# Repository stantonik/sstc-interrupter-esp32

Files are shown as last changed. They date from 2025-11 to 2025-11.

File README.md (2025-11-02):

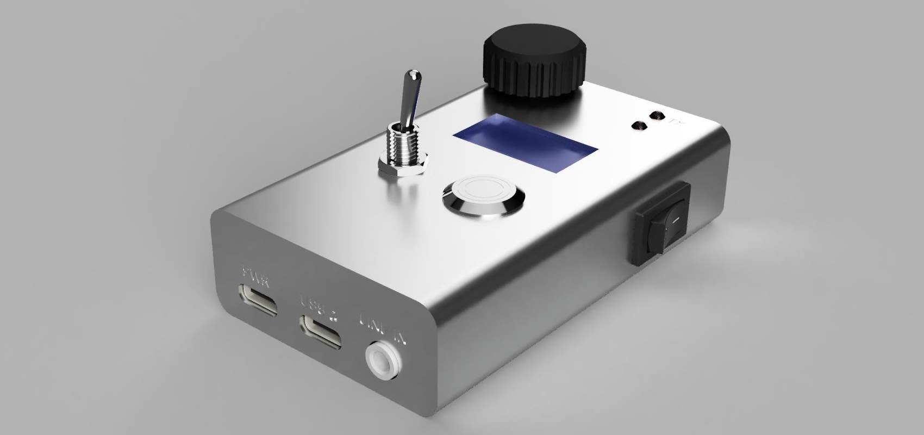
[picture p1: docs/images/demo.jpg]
demo


# sstc-interrupter-esp32

**Still in development! Maybe unstable.**

> This project implements a digital interrupter for any Solid State Tesla Coils (SSTC, DRSSTC, ...). The interrupter allows precise control over the arc output using different control modes, making it easy to experiment with pulse timing, audio modulation, or MIDI control.

## Features
- **Three Control Modes**
    - Manual: Fully custom PWM output from 0 to 20 kHz, with 1 µs minimum pulse width.
    - Line-In: Samples audio input via jack at 16 kHz, modulates PWM at 30 kHz carrier.
    - USB MIDI: Synthesizes sinusoidal notes, supports polyphonic chords, and modulates PWM at 30 kHz carrier.

- **User Interface**
    - SSD1306 64x128 monochrome display
    - Rotary encoder for navigation
    - Two triggers: toggle switch and push button
    - Nice and simple graphical interface

- **Connectivity**
    - USB-C for power input only
    - USB-C OTG/Serial for MIDI/Programming
    - 3.5 mm audio jack input
    - Toslink SPDIF output

- **Hardware Efficiency**
    - Written entirely in C using ESP-IDF
    - Real-time control via FreeRTOS
    - Optimized for ESP32-S3 hardware: LEDC, RMT, GPTIMER, ADC
    - Battery powered (200 mAh)

## RoadMap

- 📍 Implement advanced MIDI features (velocity, aftertouch)
- 📍 Implement real-time waveform visualization
- 📍 Add configuration presets and saving to flash

## Project Structure

``` text
sstc-interrupter-esp32/
├── LICENSE                   # Project license
├── README.md                 # This file
├── docs/                     # Documentation, schematics, and guides
├── firmware/                 # ESP-IDF firmware project
│   ├── CMakeLists.txt
│   ├── dependencies.lock
│   ├── main/
│   │   ├── CMakeLists.txt
│   │   ├── Kconfig.projbuild # Custom menuconfig for pinout & constraints
│   │   ├── app/              # High-level application logic
│   │   │   ├── clients/      # Protocol clients (e.g., USB MIDI)
│   │   │   ├── gui/          # Graphical User Interface (LVGL)
│   │   │   └── main.c        # Program entry point (init, orchestrate, ...)
│   │   ├── core/             # Event handling
│   │   ├── hal/              # Hardware Abstraction Layer (synth, USB, display, jack, etc.)
│   │   └── idf_component.yml
│   ├── sdkconfig
│   └── sstc_interrupter-esp32.eez-project # EEZ-Studio project for LVGL GUI design
└── hardware/
    ├── cad/                  # 3D models, STLs, and mechanical design
    └── pcb/                  # Printed Circuit Board designs and gerbers
```

## Documentation
***soon***

## Contributing
Contributions are welcome! You can help by:
- Reporting issues or bugs
- Improving UI graphics
- Optimizing PWM and audio processing
- Adding features (more control modes, presets, etc.)
- Updating documentation and schematics

**Please note:** This project involves high-voltage electronics. Take appropriate safety precautions and ensure optical isolation between the interrupter and the Tesla coil.

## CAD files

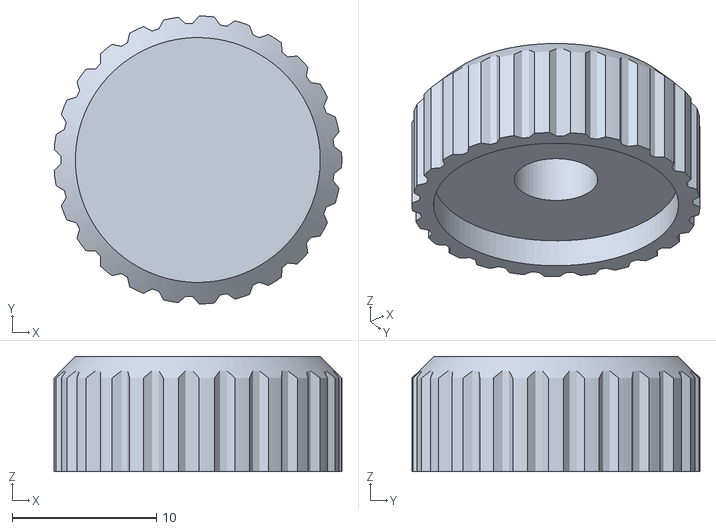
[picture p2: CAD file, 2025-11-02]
hardware/cad/stl/knob.stl
20.0 x 20.0 x 8.00

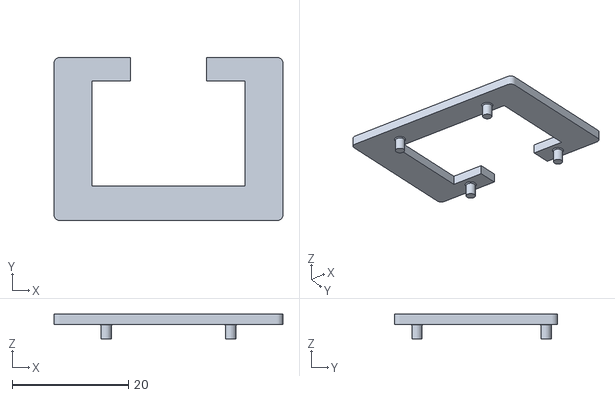
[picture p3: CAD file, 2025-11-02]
hardware/cad/stl/screen-support.stl
39.4 x 28.1 x 4.30

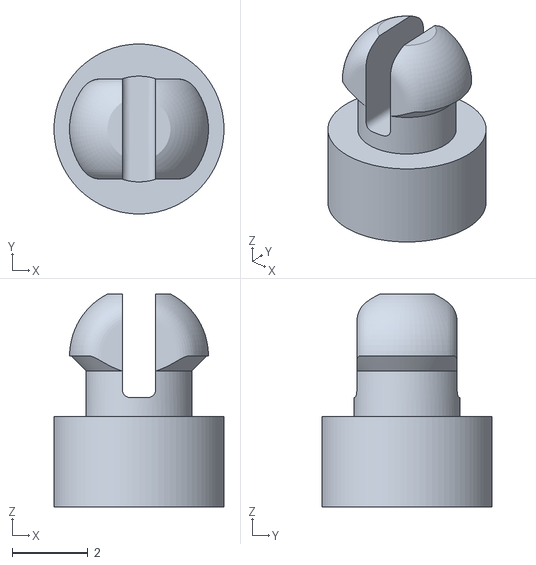
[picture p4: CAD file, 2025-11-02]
hardware/cad/stl/pcb-snap_support.stl
4.50 x 4.50 x 5.64

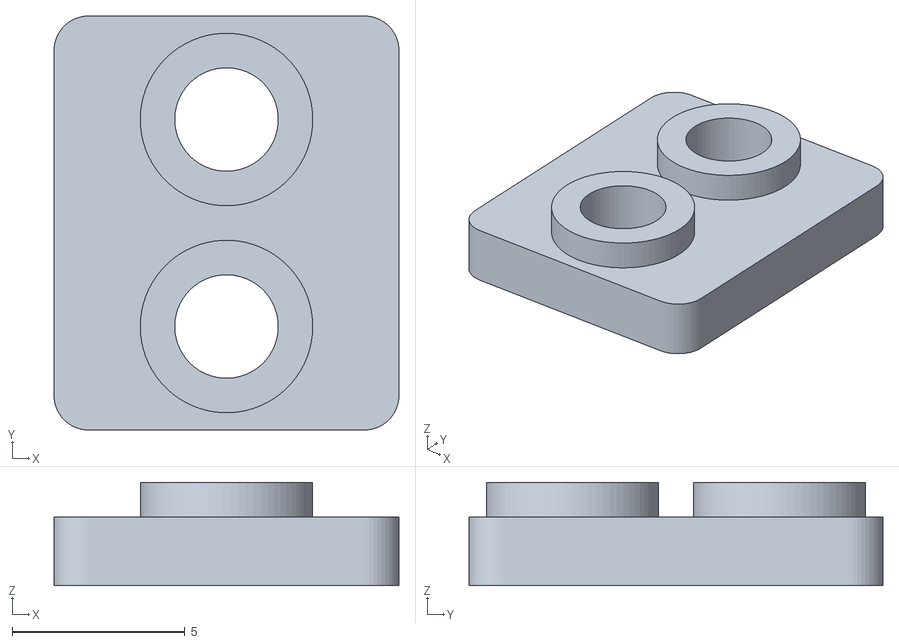
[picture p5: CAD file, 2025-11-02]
hardware/cad/stl/leds-support.stl
10.0 x 12.0 x 3.00

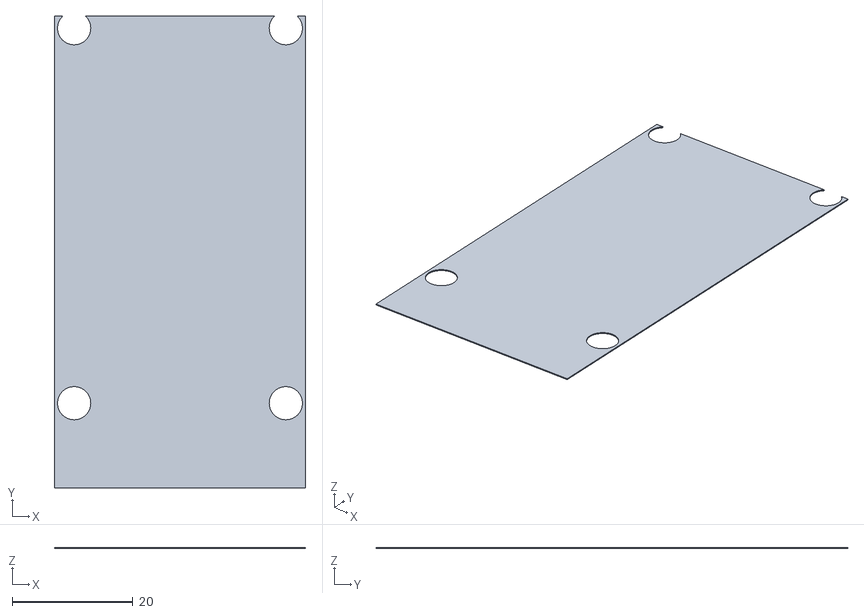
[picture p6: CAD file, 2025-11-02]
hardware/cad/stl/isolate-layer.stl
41.5 x 78.0 x 0.18

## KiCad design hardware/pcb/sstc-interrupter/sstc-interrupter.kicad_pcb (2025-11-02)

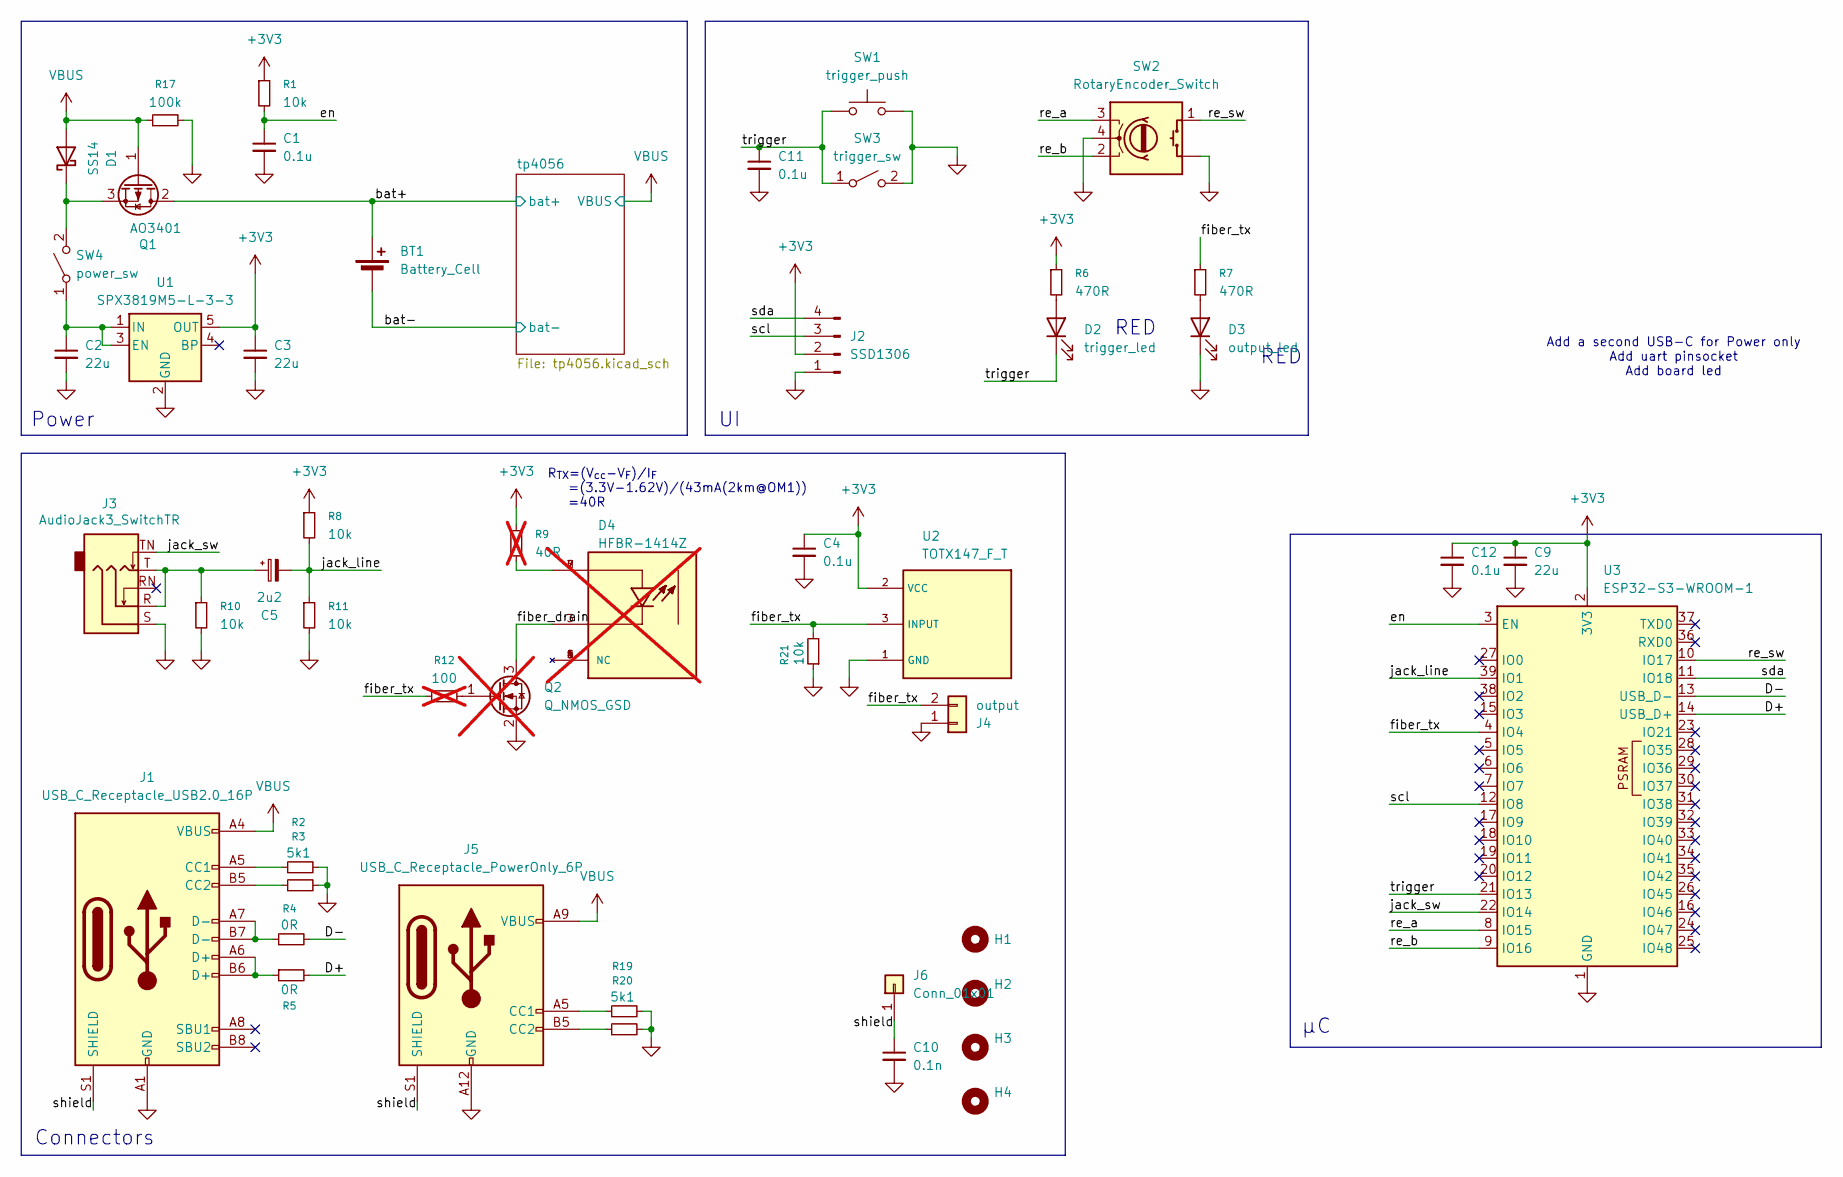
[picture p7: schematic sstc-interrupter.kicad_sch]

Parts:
BT1: Battery_Cell; JST_PH_B2B-PH-K_1x02_P2.00mm_Vertical
C1, C4, C11, C12: 0.1u; C_0603_1608Metric_Pad1.08x0.95mm_HandSolder
C2, C3, C9: 22u; C_0805_2012Metric_Pad1.18x1.45mm_HandSolder
C5: 2u2; C_Radial_D5.0mm_H11.0mm_P2.00mm
C10: 0.1n; C_0805_2012Metric_Pad1.18x1.45mm_HandSolder
D1: SS14; D_SMA
D2: trigger_led; JST_PH_B2B-PH-K_1x02_P2.00mm_Vertical
D3: output_led; JST_PH_B2B-PH-K_1x02_P2.00mm_Vertical
D4: HFBR-1414Z; OPTO_HFBR-1414Z; PARTREV February 15, 2019; not fitted
H1, H2, H3, H4: MountingHole; MountingHole_3.2mm_M3_DIN965
J1: USB_C_Receptacle_USB2.0_16P; USB_C_Receptacle_GCT_USB4105-xx-A_16P_TopMnt_Horizontal
J2: SSD1306; JST_PH_B4B-PH-K_1x04_P2.00mm_Vertical
J3: AudioJack3_SwitchTR; Jack_3.5mm_CUI_SJ1-3525N_Horizontal
J4: output; PinHeader_1x02_P2.54mm_Horizontal
J5: USB_C_Receptacle_PowerOnly_6P; USB_C_Receptacle_GCT_USB4125-xx-x-0190_6P_TopMnt_Horizontal
J6: Conn_01x01; SolderWire-0.15sqmm_1x01_D0.5mm_OD1.5mm
Q1: AO3401; SOT-23_Handsoldering
Q2: Q_NMOS_GSD; SOT-23-3; not fitted
R1, R8, R10, R11, R21: 10k; R_0603_1608Metric_Pad0.98x0.95mm_HandSolder
R2, R3, R19, R20: 5k1; R_0603_1608Metric_Pad0.98x0.95mm_HandSolder
R4, R5: 0R; R_0603_1608Metric_Pad0.98x0.95mm_HandSolder
R6, R7: 470R; R_0603_1608Metric_Pad0.98x0.95mm_HandSolder
R9: 40R; R_0603_1608Metric_Pad0.98x0.95mm_HandSolder; not fitted
R12: 100; R_0603_1608Metric_Pad0.98x0.95mm_HandSolder; not fitted
R17: 100k; R_0603_1608Metric_Pad0.98x0.95mm_HandSolder
SW1: trigger_push; JST_PH_B2B-PH-K_1x02_P2.00mm_Vertical
SW2: RotaryEncoder_Switch; JST_PH_B4B-PH-K_1x04_P2.00mm_Vertical
SW3: trigger_sw; JST_PH_B2B-PH-K_1x02_P2.00mm_Vertical
SW4: power_sw; JST_PH_B2B-PH-K_1x02_P2.00mm_Vertical
U1: SPX3819M5-L-3-3; SOT-23-5
U2: TOTX147_F_T; TOSHIBA_TORX147_F_T_
U3: ESP32-S3-WROOM-1; ESP32-S3-WROOM-1U

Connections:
+3V3: C3.1, C4.1, C9.1, C12.1, J2.2, R1.1, R6.1, R8.1, R9.1, U1.5 (OUT), U2.2 (VCC), U3.2 (3V3)
/D+: R5.2, U3.14 (USB_D+)
/D-: R4.2, U3.13 (USB_D-)
/bat+: BT1.1 (+), Q1.2 (D); also elsewhere on the board
/bat-: BT1.2 (-); also elsewhere on the board
/en: C1.1, R1.2, U3.3 (EN)
/fiber_tx: J4.2, R7.1, R12.1, R21.2, U2.3 (INPUT), U3.4 (IO4)
/jack_line: C5.2, R8.2, R11.1, U3.39 (IO1)
/jack_sw: J3.TN, U3.22 (IO14)
/re_a: SW2.3 (A), U3.8 (IO15)
/re_b: SW2.2 (B), U3.9 (IO16)
/re_sw: SW2.1 (S1), U3.10 (IO17)
/scl: J2.3, U3.12 (IO8)
/sda: J2.4, U3.11 (IO18)
/shield: C10.1, J1.S1 (SHIELD), J5.S1 (SHIELD), J6.1
/trigger: C11.1, D2.2 (K), SW1.1, SW3.1 (A), U3.21 (IO13)
GND: C1.2, C2.2, C3.2, C4.2, C9.2, C10.2, C11.2, C12.2, D3.1 (K), J1.A1 (GND), J1.A12 (GND), J1.B1 (GND), J1.B12 (GND), J2.1, J3.S, J4.1, J5.A12 (GND), J5.B12 (GND), Q2.2 (S), R2.2, R3.2, R10.2, R11.2, R17.2, R19.2, R20.2, R21.1, SW1.2, SW2. (S2), SW2.4 (C), SW3.2 (B), U1.2 (GND), U2.1 (GND), U3.1 (GND), U3.40 (GND), U3.41 (GND); also elsewhere on the board
unnamed: C5.1, J3.R, J3.T, R10.1
unnamed: D1.1 (K), Q1.3 (S), SW4.2 (B)
unnamed: D2.1 (A), R6.2
unnamed: D3.2 (A), R7.2
unnamed: D4.1 (NC), D4.4 (NC), D4.5 (NC), D4.8 (NC)
unnamed: D4.2, D4.6, D4.7, R9.2
unnamed: D4.3, Q2.3 (D)
unnamed: J1.A5 (CC1), R2.1
unnamed: J1.B5 (CC2), R3.1
unnamed: J1.A6 (D+), J1.B6 (D+), R5.1
unnamed: J1.A7 (D-), J1.B7 (D-), R4.1
unnamed: J5.A5 (CC1), R19.1
unnamed: J5.B5 (CC2), R20.1
unnamed: Q2.1 (G), R12.2
unnamed: C2.1, SW4.1 (A), U1.1 (IN), U1.3 (EN)
VBUS: D1.2 (A), J1.A4 (VBUS), J1.A9 (VBUS), J1.B4 (VBUS), J1.B9 (VBUS), J5.A9 (VBUS), J5.B9 (VBUS), Q1.1 (G), R17.1; also elsewhere on the board

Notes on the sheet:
Add a second USB-C for Power only Add uart pinsocket Add board led
Connectors
R_{TX}=(V_{cc}-V_{F})/I_{F} =(3.3V-1.62V)/(43mA(2km@OM1)) =40R
RED
Power

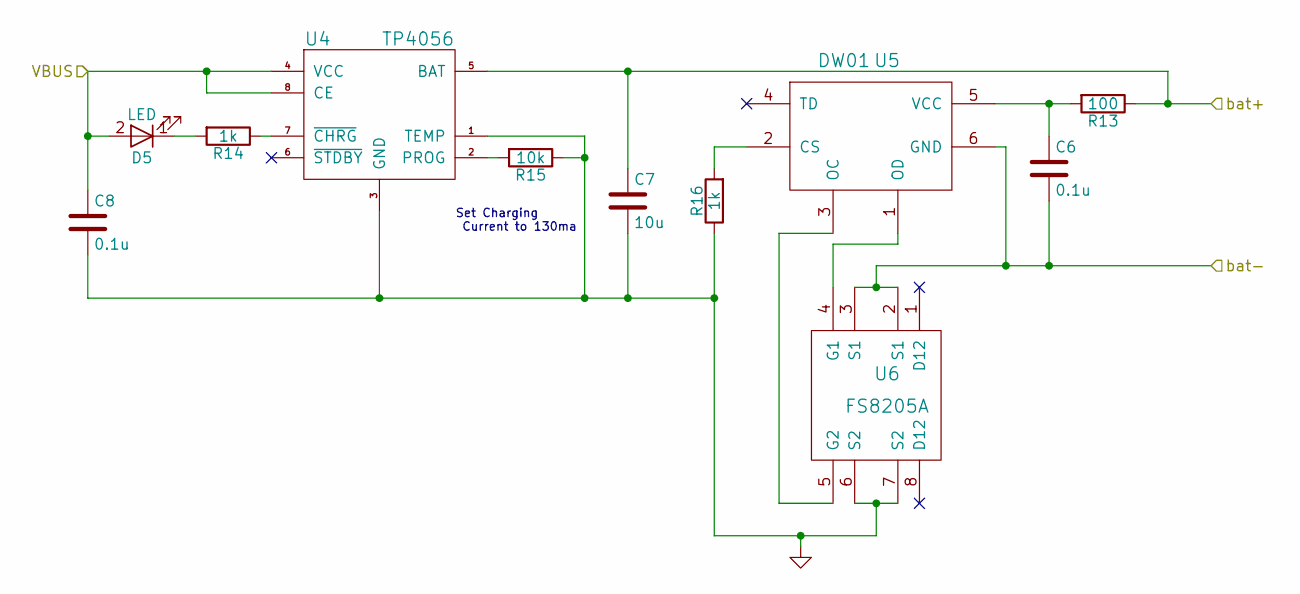
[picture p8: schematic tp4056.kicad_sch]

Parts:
C6, C8: 0.1u; C_0603_1608Metric_Pad1.08x0.95mm_HandSolder
C7: 10u; C_0805_2012Metric_Pad1.18x1.45mm_HandSolder
D5: LED; LED_0603_1608Metric_Pad1.05x0.95mm_HandSolder
R13: 100; R_0603_1608Metric_Pad0.98x0.95mm_HandSolder
R14, R16: 1k; R_0603_1608Metric_Pad0.98x0.95mm_HandSolder
R15: 10k; R_0603_1608Metric_Pad0.98x0.95mm_HandSolder
U4: TP4056; SOP-8_3.9x4.9mm_P1.27mm
U5: DW01; SOT-23-6_Handsoldering
U6: FS8205A; TSSOP-8_4.4x3mm_P0.65mm

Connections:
/bat+: C7.1, R13.1, U4.5 (BAT); also elsewhere on the board
/bat-: C6.2, U5.6 (GND), U6.2 (S1), U6.3 (S1); also elsewhere on the board
GND: C7.2, C8.2, R15.1, R16.1, U4.1 (TEMP), U4.3 (GND), U6.6 (S2), U6.7 (S2); also elsewhere on the board
unnamed: D5.1 (K), R14.2
unnamed: R15.2, U4.2 (PROG)
unnamed: R14.1, U4.7 (~CHRG)
unnamed: R16.2, U5.2 (CS)
unnamed: U5.3 (OC), U6.5 (G2)
unnamed: U5.1 (OD), U6.4 (G1)
unnamed: C6.1, R13.2, U5.5 (VCC)
VBUS: C8.1, D5.2 (A), U4.4 (VCC), U4.8 (CE); also elsewhere on the board

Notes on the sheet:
Set Charging Current to 130ma

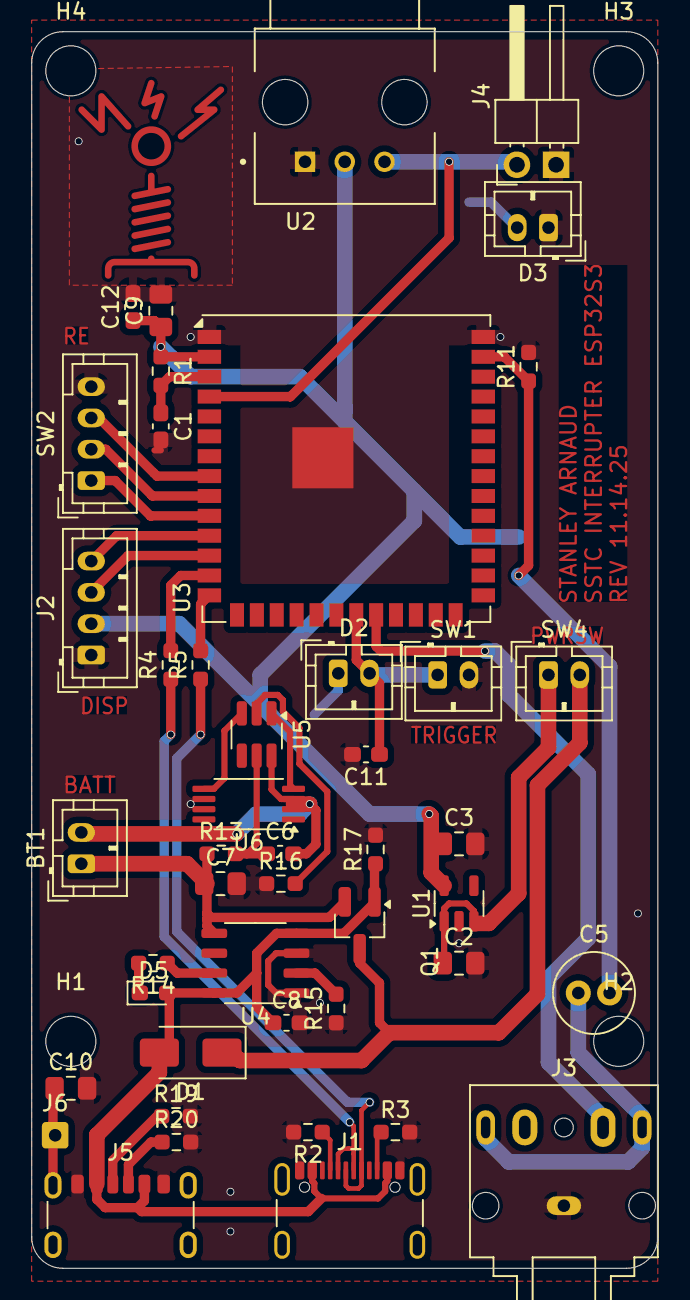
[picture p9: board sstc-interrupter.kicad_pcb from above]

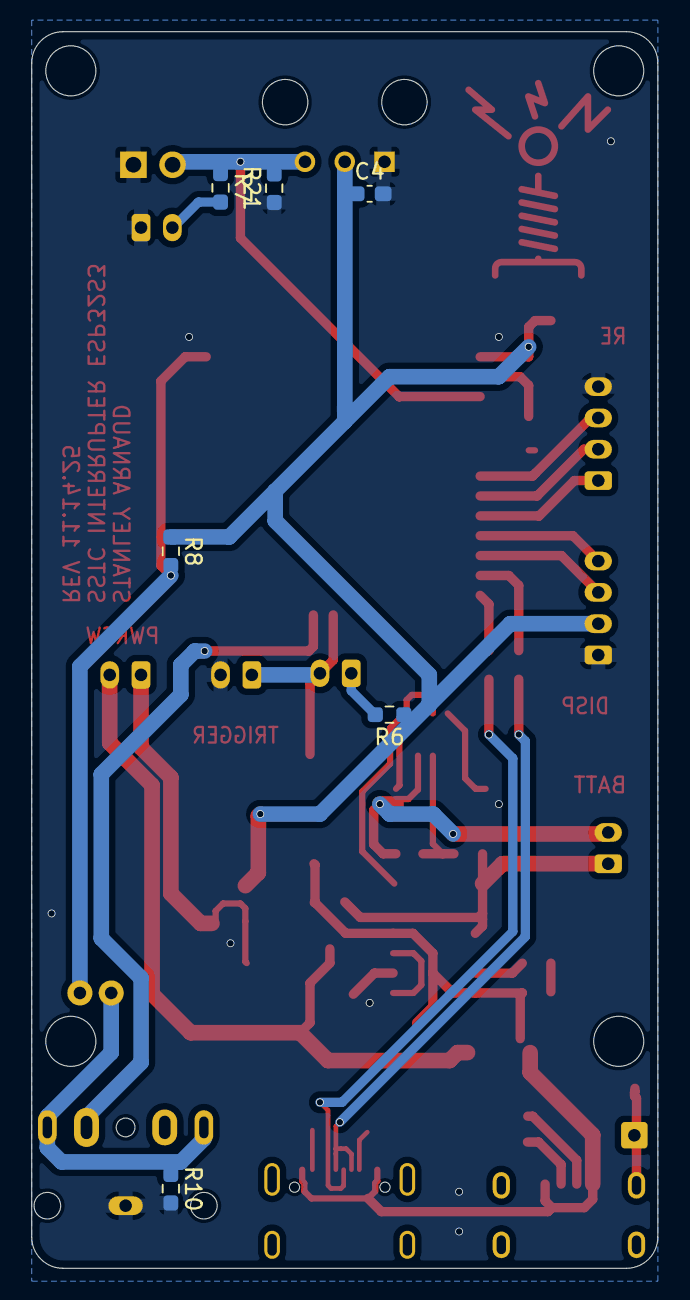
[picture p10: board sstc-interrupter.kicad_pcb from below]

Board: 2 copper layers, 40.0 x 79.0 mm, 55 parts (6 on the bottom side), 36 nets.

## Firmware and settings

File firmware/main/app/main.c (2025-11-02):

/*
 * Copyright (C) 2025 Stanley Arnaud <stantonik@stantonik-mba.local>
 *
 * Distributed under terms of the MIT license.
 */

/**
 * @file main.c
 * @brief
 *
 * @author Stanley Arnaud
 * @date 10/25/2025
 * @version 0
 */

// -----------------------------------------------------------------------------
// Includes
// -----------------------------------------------------------------------------
#include "app/clients/usb_midi.h"
#include "app/gui/knobs.h"
#include "clients/usb_midi.h"
#include "core/event_bus.h"
#include "esp_attr.h"
#include "esp_log.h"
#include "freertos/idf_additions.h"
#include "gui/menu.h"
#include "hal/audio_jack.h"
#include "hal/controls.h"
#include "hal/display.h"
#include "hal/pwm.h"
#include "hal/synth.h"
#include "hal/usb.h"

// -----------------------------------------------------------------------------
// Macros and Constants
// -----------------------------------------------------------------------------
#define TAG "main"

#define RETURN_ON_ERROR(x)                                                                                             \
    {                                                                                                                  \
        esp_err_t ret = (x);                                                                                           \
        if (ret != ESP_OK) return;                                                                                     \
    }

// -----------------------------------------------------------------------------
// Static Variables
// -----------------------------------------------------------------------------

// -----------------------------------------------------------------------------
// Static Function Declarations
// -----------------------------------------------------------------------------

// -----------------------------------------------------------------------------
// Static Function Definitions
// -----------------------------------------------------------------------------
static void midi_on_receive_cb(midi_message_t msg)
{
    if (menu_get_mode() != MENU_MODE_MIDI) return;

    static synth_note_t synth_note = {0};
    synth_note.note = msg.note % 12;
    synth_note.octave = -2 + msg.note / 12;

    if (msg.state == 1)
    {
        synth_play_note(synth_note);

        midi_msg_parsed_t parsed_msg = usb_midi_parse_msg(&msg);

        char header[16];
        snprintf(header, 16, "%s%d", parsed_msg.note, parsed_msg.octave);
        menu_set_header_text(header);
    }
    else
    {
        synth_stop_note(synth_note);
        menu_set_header_text("");
    }
}

static void knobs_on_change_cb(knobs_mask_t updated, const knob_t *knobs[])
{
    static float prf = 0;
    static uint16_t pd = 0;

    if (updated & (1 << KNOB_PRF))
    {
        prf = knobs[KNOB_PRF]->value;
    }
    if (updated & (1 << KNOB_PD))
    {
        pd = knobs[KNOB_PD]->value;
    }

    ESP_LOGI(TAG, "prf=%d, pd=%d", (int)prf, (int)pd);
    pwm_manual_update(prf, pd);
}

static IRAM_ATTR void audio_jack_out_cb(uint16_t value)
{
    // Get knob pointers
    const knob_t *knobs[KNOB_COUNT];
    knobs_get_values(knobs);

    // Center input around mid
    int16_t centered_val = (int16_t)value - AUDIO_JACK_OUT_MID;

    // Apply pseudo-exponential gain for GDB knob
    int16_t gdb = knobs[KNOB_GDB]->value;  // Gdb range: -50..+50
    int32_t temp = centered_val;
    if (gdb > 0) {
        temp = temp + (temp * gdb * gdb) / 2500; // stronger amplification
    } else if (gdb < 0) {
        temp = temp - (temp * gdb * gdb) / 2500; // stronger attenuation
    }
    centered_val = (int16_t)temp;

    // Add mid back
    int16_t val = centered_val + AUDIO_JACK_OUT_MID;

    // Clamp to valid output range
    if (val < 0) val = 0;
    if (val > AUDIO_JACK_OUT_MAX) val = AUDIO_JACK_OUT_MAX;

    // Convert to PWM duty (uint8_t) and apply power knob
    uint32_t dt = (uint32_t)val * PWM_MOD_DUTY_MAX / AUDIO_JACK_OUT_MAX;
    dt = dt * knobs[KNOB_PWR]->value / knobs[KNOB_PWR]->max_physical;

    // Update PWM
    pwm_modulation_update((uint8_t)(dt / 2));
}

static IRAM_ATTR void synth_on_sampling_cb(uint16_t value)
{
    const knob_t *knobs[KNOB_COUNT];
    knobs_get_values(knobs);

    uint32_t dt = (uint32_t)value * PWM_MOD_DUTY_MAX / SYNTH_OUT_MAX;
    dt = dt * knobs[KNOB_PWR]->value / knobs[KNOB_PWR]->max_physical;
    pwm_modulation_update((uint8_t)(dt / 2));
}

// -----------------------------------------------------------------------------
// Function Definitions
// -----------------------------------------------------------------------------
void app_main(void)
{
    ESP_LOGI(TAG, "Firmware starting...");

    // Initialize Serial bridge at first
    RETURN_ON_ERROR(usb_init_serial());

    // Create event queue
    RETURN_ON_ERROR(event_bus_init());

    // Initialize hardware
    RETURN_ON_ERROR(controls_init());
    RETURN_ON_ERROR(audio_jack_init());
    RETURN_ON_ERROR(display_init());
    RETURN_ON_ERROR(pwm_init());
    audio_jack_set_output_cb(audio_jack_out_cb);

    uint8_t ctrl_state = controls_get_state();

    // Initialize GUI
    RETURN_ON_ERROR(menu_init());
    knobs_set_on_change_cb(knobs_on_change_cb);
    RETURN_ON_ERROR(knobs_init());

    // Check if trigger was pressed on boot
    if (ctrl_state & CONTROLS_FLAG_TRIGGER_PRESSED)
    {
        menu_display_msg_box("Release trigger\non boot!", 0);
        ESP_LOGI(TAG, "Triggered on boot! Please release it.");
        while (ctrl_state & CONTROLS_FLAG_TRIGGER_PRESSED)
        {
            ctrl_state = controls_get_state();
            vTaskDelay(pdMS_TO_TICKS(10));
        }
        menu_hide_msg_box();
    }

    // Configure USB Host Library if encoder switch was not pressed on boot
    if (ctrl_state & CONTROLS_FLAG_RE_PRESSED)
    {
        menu_display_msg_box("Debug mode\n(MIDI disabled)", 1500);
        ESP_LOGI(TAG, "Booted in debug mode (MIDI disabled)");
    }
    else
    {
        ESP_LOGI(TAG, "Booted in normal operation");
        RETURN_ON_ERROR(usb_free_serial());
        if (usb_init_host() != ESP_OK)
        {
            usb_init_serial();
            ESP_LOGW(TAG, "Could not install USB host");
        }

        RETURN_ON_ERROR(usb_midi_init());
        usb_midi_set_on_receive_cb(midi_on_receive_cb);

        RETURN_ON_ERROR(synth_init());
        synth_set_on_sampling_cb(synth_on_sampling_cb);
    }

    event_t e;
    while (1)
    {
        event_bus_dispatch(&e, portMAX_DELAY);

        if (e.source == EVENT_SRC_CONTROLS)
        {
            switch (e.type)
            {
            case CONTROLS_EVENT_TRIGGER_PRESSED:
                ESP_LOGI(TAG, "Armed");
                menu_set_state(MENU_STATE_ARMED);
                pwm_enable();
                break;
            case CONTROLS_EVENT_TRIGGER_RELEASED:
                ESP_LOGI(TAG, "Disarmed");
                menu_set_state(MENU_STATE_IDLE);
                pwm_disable();
                break;
            default:
                break;
            }
        }
        else if (e.source == EVENT_SRC_AUDIO_JACK)
        {
            switch (e.type)
            {
            case AUDIO_JACK_EVENT_PLUGGED:
                if (menu_get_mode() != MENU_MODE_MANUAL) break;
                ESP_LOGI(TAG, "Line-IN mode");
                menu_set_mode(MENU_MODE_AUDIO_JACK, true);
                audio_jack_start_listen();
                pwm_set_mode(PWM_MODE_MODULATION);
                break;
            case AUDIO_JACK_EVENT_UNPLUGGED:
                if (menu_get_mode() != MENU_MODE_AUDIO_JACK) break;
                ESP_LOGI(TAG, "Manual mode");
                menu_set_mode(MENU_MODE_MANUAL, true);
                audio_jack_stop_listen();
                pwm_set_mode(PWM_MODE_MANUAL);
                break;
            default:
                break;
            }
        }
        else if (e.source == EVENT_SRC_USB_MIDI)
        {
            switch (e.type)
            {
            case USB_MIDI_EVENT_CONNECTED:
                if (menu_get_mode() != MENU_MODE_MANUAL) break;
                ESP_LOGI(TAG, "MIDI mode");
                menu_set_mode(MENU_MODE_MIDI, true);
                pwm_set_mode(PWM_MODE_MODULATION);
                synth_enable();
                break;
            case USB_MIDI_EVENT_DISCONNECTED:
                if (menu_get_mode() != MENU_MODE_MIDI) break;
                ESP_LOGI(TAG, "Manual mode");
                menu_set_mode(MENU_MODE_MANUAL, true);
                synth_disable();
                pwm_set_mode(PWM_MODE_MANUAL);
                break;
            default:
                break;
            }
        }
    }

    ESP_LOGI(TAG, "Firmware exited");
}

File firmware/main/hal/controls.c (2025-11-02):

/*
 * Copyright (C) 2025 Stanley Arnaud <stantonik@stantonik-mba.local>
 *
 * Distributed under terms of the MIT license.
 */

/**
 * @file controls.c
 * @brief
 *
 * @author Stanley Arnaud
 * @date 10/24/2025
 * @version 0
 */

// -----------------------------------------------------------------------------
// Includes
// -----------------------------------------------------------------------------
#include "controls.h"
#include "esp_log.h"
#include "freertos/FreeRTOS.h"
#include "button_gpio.h"
#include "core/event_bus.h"
#include "encoder.h"
#include "esp_check.h"
#include "iot_button.h"

// -----------------------------------------------------------------------------
// Macros and Constants
// -----------------------------------------------------------------------------
#define TAG "controls"

#define PIN_TRIGGER CONFIG_INTERRUPTER_PIN_TRIGGER

#define PIN_RE_A CONFIG_INTERRUPTER_PIN_RE_A
#define PIN_RE_B CONFIG_INTERRUPTER_PIN_RE_B
#define PIN_RE_SW CONFIG_INTERRUPTER_PIN_RE_SW

// -----------------------------------------------------------------------------
// Static Variables
// -----------------------------------------------------------------------------
static rotary_encoder_t re = {0};
static QueueHandle_t re_queue = NULL;

static button_handle_t trigger_btn = NULL;

static volatile uint8_t state = 0;

// -----------------------------------------------------------------------------
// Static Function Declarations
// -----------------------------------------------------------------------------

// -----------------------------------------------------------------------------
// Static Function Definitions
// -----------------------------------------------------------------------------
static void button_down_cb(void *arg, void *usr_data)
{
    button_handle_t btn = (button_handle_t)arg;
    event_t event = {.source = EVENT_SRC_CONTROLS};

    if (btn == trigger_btn)
    {
        ESP_LOGI(TAG, "Trigger pressed");
        state |= CONTROLS_FLAG_TRIGGER_PRESSED;
        event.type = CONTROLS_EVENT_TRIGGER_PRESSED;
    }

    event_bus_publish(&event);
}

static void button_up_cb(void *arg, void *usr_data)
{
    button_handle_t btn = (button_handle_t)arg;
    event_t event = {.source = EVENT_SRC_CONTROLS};

    if (btn == trigger_btn)
    {
        ESP_LOGI(TAG, "Trigger released");
        state &= ~CONTROLS_FLAG_TRIGGER_PRESSED;
        event.type = CONTROLS_EVENT_TRIGGER_RELEASED;
    }

    event_bus_publish(&event);
}

static void re_task(void *pvParam)
{
    rotary_encoder_event_t re_event;
    event_t event = {.source = EVENT_SRC_CONTROLS};

    while (1)
    {
        xQueueReceive(re_queue, &re_event, portMAX_DELAY);

        switch (re_event.type)
        {
        case RE_ET_BTN_PRESSED:
            event.type = CONTROLS_EVENT_RE_BTN_PRESSED;
            state |= CONTROLS_FLAG_RE_PRESSED;
            break;
        case RE_ET_BTN_RELEASED:
            event.type = CONTROLS_EVENT_RE_BTN_RELEASED;
            state &= ~CONTROLS_FLAG_RE_PRESSED;
            break;
        case RE_ET_BTN_CLICKED:
            event.type = CONTROLS_EVENT_RE_BTN_CLICKED;
            break;
        case RE_ET_BTN_LONG_PRESSED:
            event.type = CONTROLS_EVENT_RE_BTN_LONG_PRESSED;
            break;
        case RE_ET_CHANGED:
            event.type = CONTROLS_EVENT_RE_CHANGED;
            event.value = re_event.diff;
            break;
        default:
            break;
        }

        event_bus_publish(&event);
    }
}

// -----------------------------------------------------------------------------
// Function Definitions
// -----------------------------------------------------------------------------
esp_err_t controls_init(void)
{
    // Rotary encoder
    re_queue = xQueueCreate(4, sizeof(rotary_encoder_event_t));
    ESP_RETURN_ON_ERROR(rotary_encoder_init(re_queue), TAG, "Failed to initialize rotary encoder driver");

    re.pin_a = PIN_RE_A;
    re.pin_b = PIN_RE_B;
    re.pin_btn = PIN_RE_SW;

    ESP_RETURN_ON_ERROR(rotary_encoder_add(&re), TAG, "Failed to create rotary encoder instance");

    ESP_RETURN_ON_FALSE(xTaskCreate(re_task, TAG, configMINIMAL_STACK_SIZE * 8, NULL, 5, NULL) == pdPASS,
        ESP_ERR_NO_MEM, TAG, "Failed to create encoder task");

    // Trigger (switch and push button)
    button_config_t btn_cfg = {0};
    button_gpio_config_t gpio_cfg = {
        .gpio_num = PIN_TRIGGER,
        .active_level = 0,
    };
    ESP_RETURN_ON_ERROR(
        iot_button_new_gpio_device(&btn_cfg, &gpio_cfg, &trigger_btn), TAG, "Failed to create trigger button instance");

    iot_button_register_cb(trigger_btn, BUTTON_PRESS_UP, NULL, button_up_cb, (void *)trigger_btn);
    iot_button_register_cb(trigger_btn, BUTTON_PRESS_DOWN, NULL, button_down_cb, (void *)trigger_btn);

    ESP_LOGI(TAG, "Initializaion succeeded");

    return ESP_OK;
}

uint8_t controls_get_state(void) { return state; }

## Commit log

2025-11-02 Initial commit
    Proof of concept demonstrating functional hardware and software,
    including three operational modes. Some knob actions and UI features
    are still missing or incomplete.
    [isolate-layer.stl, knob.stl, leds-support.stl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]
2025-11-02 fix(gui): correct behavior of power and gdb knob effects
    GDB and PWR knobs now affect the output signal in MIDI mode and LINE-IN mode. But MIDI still needs a GDB knob.
    [main.c]
